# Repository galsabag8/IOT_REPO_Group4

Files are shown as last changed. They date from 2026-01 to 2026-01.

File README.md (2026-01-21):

## Conducting Baton Project by : Dor Abotbol, Shahar Payevsky & Gal Sabag
  
## Details about the project
In this project, we have developed an interactive system for learning musical conducting. The system allows the user to load a MIDI file and perform conducting gestures using a dedicated hardware baton. 
A custom-built GUI visualizes the conductor's movements in real-time to provide immediate feedback. Crucially, the system analyzes the user's gestures to dynamically adjust the music playback speed, ensuring the orchestra plays in sync with the conductor's rhythm.
 
## Folder description :
* Documentation: wiring diagram + basic operating instructions
* Unit Tests: tests for individual hardware components (input / output devices)
* App: includes the source code for the app code, the GUI written in HTML, the backend in python (Flask), and config file containing parameters for the code configuration
* Code : includes ESP32 source code for the esp side (firmware), and config file containing parameters for the code configuration 
* Assets: MIDI files used in this project

## Hardware we used in the project:
* ESP32
* IMU 9 degrees of freedom - type BMX055
* Button

## Arduino/ESP32 libraries used in this project:
* SPI (Standard Arduino/ESP32 Core)
* Madgwick Algorithm - (Local implementation included in source)

Implementation Note:

Unlike standard implementations that rely on external sensor libraries (e.g., Adafruit), this project utilizes direct register access via SPI to communicate with the IMU sensors. This ensures minimal latency and optimized high-speed data acquisition required for real-time conducting.
Sensor fusion is handled via a local implementation of the Madgwick algorithm, adapted directly from the original source code rather than using the pre-compiled library.

## Connection diagram:
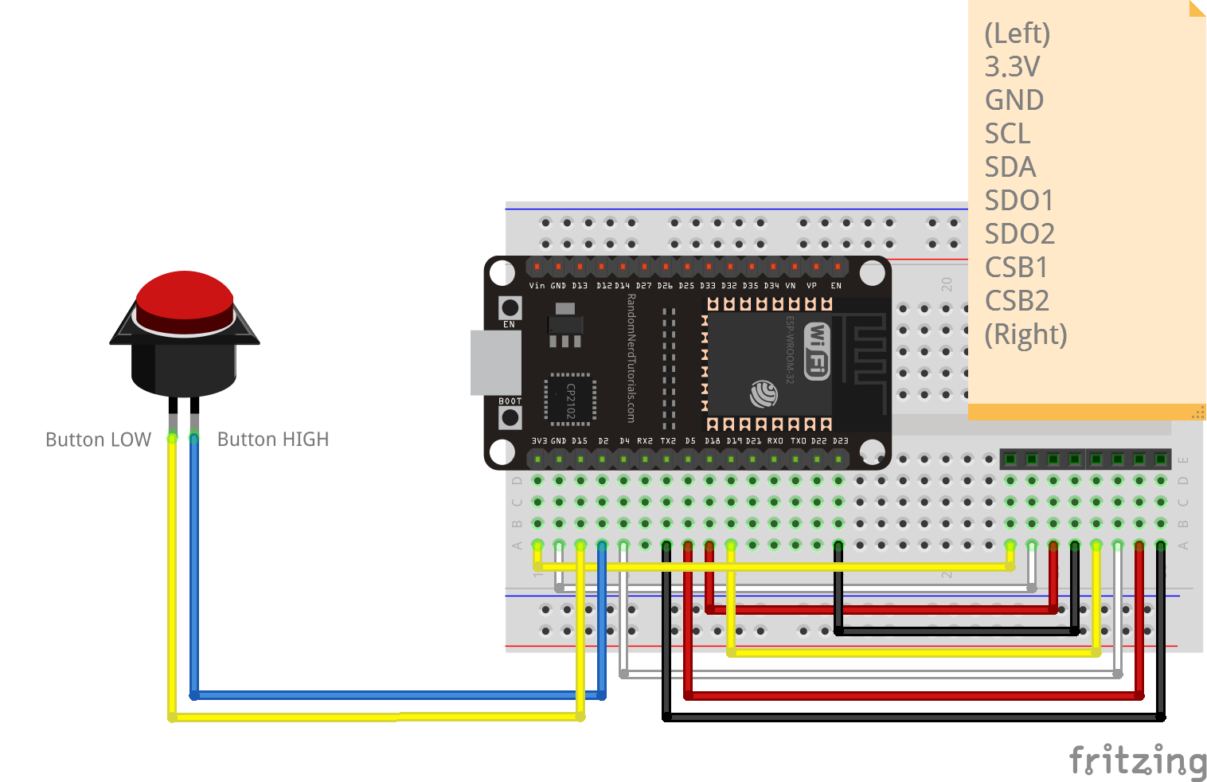
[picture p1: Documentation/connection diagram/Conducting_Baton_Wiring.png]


## Project Poster:
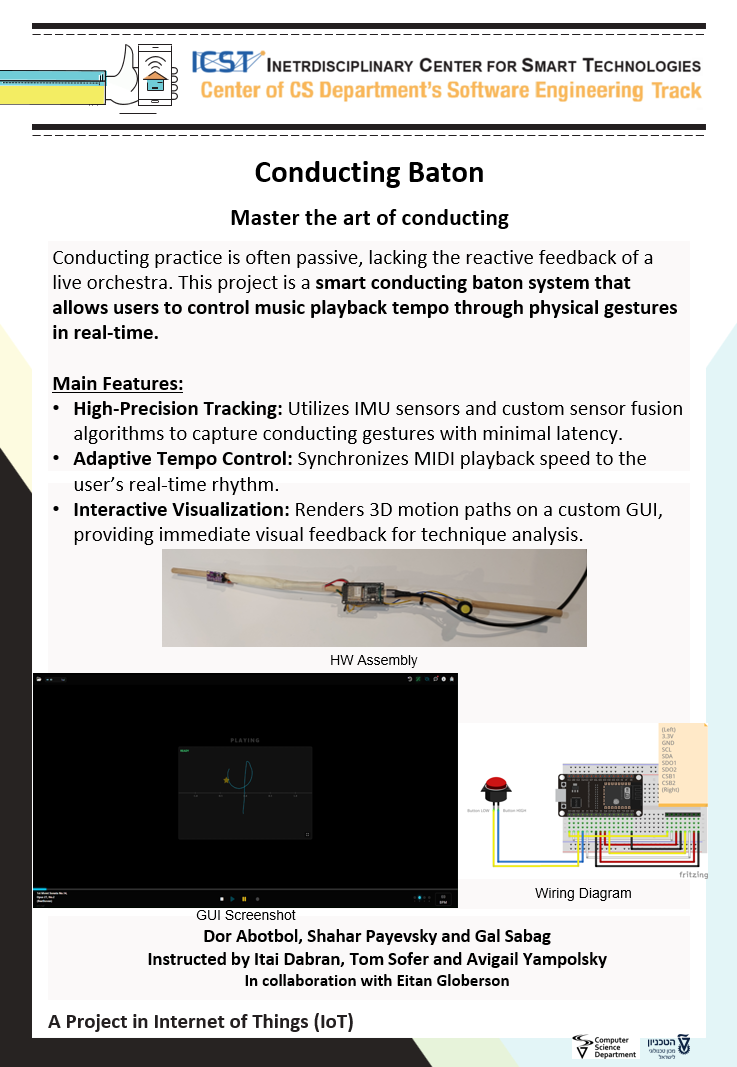
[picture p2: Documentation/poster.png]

 
This project is part of ICST - The Interdisciplinary Center for Smart Technologies, Taub Faculty of Computer Science, Technion
https://icst.cs.technion.ac.il/

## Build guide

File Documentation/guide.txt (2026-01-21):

Quick Guide:
Visualization: Click the eye to enable the 3D trail.
Calibration: Press R repeatedly until the wand appears stable (only relevant when visualization is open)
Confirm: Press Enter to lock calibration (only relevant when visualization is open)
Upload: Open a MIDI file (File button)
Start Warm‑Up: Press the wand button to begin warm‑up.
Perform: Do a full "box" motion (by the detected weight / conducting range). Music starts after warm‑up completes.
Record: Arm recording (red circle) before starting playback to save a CSV log of wand data and timing for later analysis.
Replay:Upload the original MIDI together with its CSV log to replay a recorded session visually and aurally.

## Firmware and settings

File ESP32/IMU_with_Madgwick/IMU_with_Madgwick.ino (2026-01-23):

/*
 * Project: Conductors Wand - Hybrid V1 (Vis + BPM)
 * Features: 
 * - High-speed Motion Data (for Visualization)
 * - Real-time BPM Calculation (for Music Control)
 * - Dual Filtering (Responsive for Vis, Smooth for Beats)
 */

#include <SPI.h>
#include "MadgwickAlgo.h"
#include "WeightDetectAlgo.h"
#include "config.h"

// --- Global params, defined as extern in config.h ---
bool DEBUG_MODE = false;
float CURRENT_THRESHOLD = W4_B1_THRESHOLD;

// --- Calibration Variables ---
bool gravity_calibrated = false;
int calibration_count = 0;
float gravity_accumulator = 0;
float gravity_mag = 9.80665f; // Default, will be updated

// --- Smoothing Constants ---
float accel_mag_history[SMOOTH_WINDOW] = {0};
int smooth_idx = 0;

// --- Global Variable for Time Signature ---
int TIME_SIGNATURE = 4; // Default to 4/4. Can be changed via Serial command later.
int next_expected_beat = 1;
int warmup_beats_target = 4;   
int warmup_beats_remaining = 4; //Number of beats remaining to complete warmup

// --- Beat Detection Variables ---
unsigned long last_beat_time = 0;
unsigned long last_valley_time = 0;

float smoothed_bpm = 60;
bool isPauseSent = false;

unsigned long beat_intervals[NUM_BEATS_AVG]; 
int beat_idx = 0;                      

unsigned long last_print_time = 0;

// Timing
unsigned long last_loop_time = 0;
float dt = 0.01f;
// --- Smoothed Accel Magnitude Variables ---
const int RECENT_HISTORY_SIZE = 20;
float recent_magnitudes[RECENT_HISTORY_SIZE] = {0};
int recent_idx = 0;

// Button LOGIC
bool buttonStatus = false;      // The parameter to toggle
int buttonReader;              // Current reading
int lastbuttonReader = LOW;    // Previous reading (Default LOW because of Pull-Down)
bool buttonEnabled = false;    // To track if button logic is active
bool firstButtonPress = true;  // Track if this is the first press

struct IMUData {
  float ax_phys, ay_phys, az_phys; // Physical acceleration (g)
  float gx_phys, gy_phys, gz_phys; // Physical gyroscope (deg/s)
  float gx_rad, gy_rad, gz_rad;    // Gyroscope in radians (rad/s)
};

IMUData currentIMUData;

struct VisualizationData {
  float x_vis, y_vis, z_vis;
  float screen_x, screen_y, screen_z;
};

VisualizationData currentVisData;

struct AccelerationData {
  float magnitude;
  float gyro_mag;
};

AccelerationData currentAccelData;

// --- State Definitions + variables ---
enum SystemState {
    STATE_IDLE,
    STATE_WARMUP,
    STATE_PLAYBACK
};

SystemState currentState = STATE_IDLE;
bool isGUICalibrationInProgress = false;
bool isFileLoaded = false;
bool sendConnectionStatus = true;
int connectionStatusTimeCounter = 0;


// --- Prototypes ---
void writeRegister(int csPin, byte reg, byte val, bool isAccel);
void readSensor(int csPin, byte startReg, int16_t *x, int16_t *y, int16_t *z, bool isAccel);
void updateBPM();
void detectBeat(float x, float z, float gyro_mag, float smoothed_mag);
bool handleMetric2(float x, float z, float magnitude, float gyro_mag);
bool handleMetric3(float x, float z, float magnitude, float gyro_mag);
bool handleMetric4(float x, float z, float magnitude, float gyro_mag);

void setup() {
  // 1. High Speed Serial (Matches Friend's code)
  Serial.begin(921600); 
  
  pinMode(CS_ACCEL, OUTPUT);
  pinMode(CS_GYRO, OUTPUT);
  pinMode(CS_MAG, OUTPUT);

  //Setup Button Pins
  // Configure D2 as a power source
  pinMode(SOURCE_PIN, OUTPUT);
  // Configure D15 as input with internal resistor to GND, If the button is NOT pressed, this pin will read LOW (0).
  pinMode(SENSING_PIN, INPUT_PULLDOWN);
  
  digitalWrite(CS_MAG, HIGH); 
  digitalWrite(CS_ACCEL, HIGH);
  digitalWrite(CS_GYRO, HIGH);
  digitalWrite(SOURCE_PIN, HIGH);
  
  delay(100); 

  // --- 2. Configure ACCEL (+/- 4g) ---
  SPI.begin(SPI_CLK, MISO_ACCEL, SPI_MOSI, CS_ACCEL);
  writeRegister(CS_ACCEL, 0x0F, 0x05, true); // Range +/- 4g
  writeRegister(CS_ACCEL, 0x10, 0x0C, true); // BW 125Hz
  SPI.end();

  delay(50);

  // --- 3. Configure GYRO (+/- 2000 dps) ---
  SPI.begin(SPI_CLK, MISO_GYRO, SPI_MOSI, CS_GYRO);
  writeRegister(CS_GYRO, 0x0F, 0x00, false); // Range +/- 2000dps
  writeRegister(CS_GYRO, 0x10, 0x02, false); // BW 116Hz
  SPI.end();
  
  delay(100); 
}

void loop() {
  // Always check for Serial commands regardless of state
  handleSerialCommands();
  
  // Check Button State
  checkButton();

  // 100Hz Loop
  unsigned long current_time = micros();
  if (current_time - last_loop_time < LOOP_DELAY_US) return;
  last_loop_time = micros();
  last_loop_time = current_time;

  readIMUData();

  if (!gravity_calibrated) {
    performGravityCalibration();
    return; // Wait until calibration is finished
  }

  // --- Run Embedded Algorithm (from MadgwickAlgo.cpp) ---
  updateOrientationAndLinearAccel();

  updateVisData();

  updateAndSmoothAccelMagnitude();

  //--- OUTPUT 1: Visualization Data (CSV) ---
  printXYZOutput();

  switch(currentState) {
    case STATE_IDLE:
      if (sendConnectionStatus) {
        connectionStatusTimeCounter++;
        if (connectionStatusTimeCounter >= 100) {
          connectionStatusTimeCounter = 0;
          Serial.println("STATUS: CONNECTED");
        }
      }
      return;
    case STATE_WARMUP:
      detectBeat(currentVisData.screen_x, 
                currentVisData.screen_z, 
                currentAccelData.gyro_mag, 
                currentAccelData.magnitude);
      return;
    case STATE_PLAYBACK:
      detectBeat(currentVisData.screen_x, 
                currentVisData.screen_z, 
                currentAccelData.gyro_mag, 
                currentAccelData.magnitude);
      if (millis() - last_beat_time > BPM_TIMEOUT) {
        printBPMOutput();
      }
      break;
    default:
      break;
  }
}

// --- Task: Serial Command Handling ---
void handleSerialCommands() {
  // --- 1. Check for incoming Command (Non-blocking) ---
  if (Serial.available() > 0) {
    String input = Serial.readStringUntil('\n');
    input.trim(); 

    if (input.equals("RESET")) {
      //If we got reset command from the GUI, reset the system state and variables
      // currentState = STATE_IDLE;
      // isGUICalibrationInProgress = false;
      // isFileLoaded = false;
      // firstButtonPress = true;
      // return;
      ESP.restart();
    }
    if (input.startsWith("PAUSE:")) {
      resetBeatDetectionState();
      int new_target = input.substring(6).toInt();
      warmup_beats_target = TIME_SIGNATURE + new_target - 1;
      warmup_beats_remaining = TIME_SIGNATURE + new_target - 1;
      next_expected_beat = 1;
      updateCurrentThreshold();
      currentState = STATE_WARMUP;
    }
    if (input.equals("CLOSING APP")) {
      ESP.restart();
    }
    if (input.equals("DEBUG:ON")) {
      DEBUG_MODE = true;
    }
    if (input.equals("DEBUG:OFF")) {
      DEBUG_MODE = false;
    }
    if (input.equals("WAND STATUS ACK")) {
      sendConnectionStatus = false;
      return;
    }
    if (input.equals("CALIBRATION STARTED")) {
      isGUICalibrationInProgress = true;
    }
    if (input.equals("CALIBRATION FINISHED")) {
      isGUICalibrationInProgress = false;
    }
    // Protocol: "SET_SIG:3"
    if (input.startsWith("WEIGHT:")) {
      int new_sig = input.substring(7).toInt();
      if (new_sig >= 2 && new_sig <= 4) {
        TIME_SIGNATURE = new_sig;
        next_expected_beat = 1; // Reset beat counter
        updateCurrentThreshold();
        isFileLoaded = true;
        warmup_beats_remaining = new_sig;
        warmup_beats_target = new_sig;
      }
    }
  }
}

void readIMUData() {
  int16_t raw_ax, raw_ay, raw_az;
  int16_t raw_gx, raw_gy, raw_gz;

  // --- Read Raw Data ---
  SPI.begin(SPI_CLK, MISO_ACCEL, SPI_MOSI, CS_ACCEL);
  readSensor(CS_ACCEL, 0x02, &raw_ax, &raw_ay, &raw_az, true);
  SPI.end(); 
  
  SPI.begin(SPI_CLK, MISO_GYRO, SPI_MOSI, CS_GYRO);
  readSensor(CS_GYRO, 0x02, &raw_gx, &raw_gy, &raw_gz, false);
  SPI.end();

  // --- Convert to Physical ---
  currentIMUData.ax_phys = raw_ax * ACCEL_SCALE;
  currentIMUData.ay_phys = raw_ay * ACCEL_SCALE;
  currentIMUData.az_phys = raw_az * ACCEL_SCALE;
  currentIMUData.gx_phys = raw_gx * GYRO_SCALE;
  currentIMUData.gy_phys = raw_gy * GYRO_SCALE;
  currentIMUData.gz_phys = raw_gz * GYRO_SCALE;
  currentIMUData.gx_rad = currentIMUData.gx_phys * (M_PI / 180.0f);
  currentIMUData.gy_rad = currentIMUData.gy_phys * (M_PI / 180.0f);
  currentIMUData.gz_rad = currentIMUData.gz_phys * (M_PI / 180.0f);
}

void performGravityCalibration() {
  float current_mag = sqrt(currentIMUData.ax_phys*currentIMUData.ax_phys 
                          + currentIMUData.ay_phys*currentIMUData.ay_phys 
                          + currentIMUData.az_phys*currentIMUData.az_phys);
      gravity_accumulator += current_mag;
      calibration_count++;
      
      if (calibration_count >= 100) {
          gravity_mag = gravity_accumulator / 100.0f;
          gravity_calibrated = true;
      }
}

void updateVisData() {
  // 5. Visualization Data [cite: 36]
  currentVisData.x_vis = 1.0f - 2.0f * (q2 * q2 + q3 * q3);
  currentVisData.y_vis = 2.0f * (q1 * q2 + q0 * q3);
  currentVisData.z_vis = 2.0f * (q1 * q3 - q0 * q2);

  currentVisData.screen_x = -currentVisData.y_vis;
  currentVisData.screen_y = currentVisData.x_vis;
  currentVisData.screen_z = -currentVisData.z_vis;
}

void updateOrientationAndLinearAccel() {
  MadgwickUpdate(currentIMUData.gx_rad, 
                  currentIMUData.gy_rad, 
                  currentIMUData.gz_rad, 
                  currentIMUData.ax_phys, 
                  currentIMUData.ay_phys, 
                  currentIMUData.az_phys,  
                  dt);

  // 3. Gravity Vector from Quaternions [cite: 33-35]
  float gravity_x = 2.0f * (q1 * q3 - q0 * q2);
  float gravity_y = 2.0f * (q0 * q1 + q2 * q3);
  float gravity_z = q0 * q0 - q1 * q1 - q2 * q2 + q3 * q3;

  // 4. Linear Acceleration (Subtract measured gravity)
  currentIMUData.ax_phys = currentIMUData.ax_phys - (gravity_x * gravity_mag);
  currentIMUData.ay_phys = currentIMUData.ay_phys - (gravity_y * gravity_mag);
  currentIMUData.az_phys = currentIMUData.az_phys - (gravity_z * gravity_mag);
}

void updateAndSmoothAccelMagnitude() {
  // Simple Smoothing for Accel Magnitude
  float raw_mag = sqrt(currentIMUData.ax_phys*currentIMUData.ax_phys 
                    + currentIMUData.ay_phys*currentIMUData.ay_phys 
                    + currentIMUData.az_phys*currentIMUData.az_phys);

   // Store in recent history
  recent_magnitudes[recent_idx] = raw_mag;
  recent_idx = (recent_idx + 1) % RECENT_HISTORY_SIZE;

  accel_mag_history[smooth_idx] = raw_mag;
  smooth_idx = (smooth_idx + 1) % SMOOTH_WINDOW;
  float smooth_mag = 0;
  for(int i=0; i<SMOOTH_WINDOW; i++) smooth_mag += accel_mag_history[i];
  smooth_mag /= SMOOTH_WINDOW;

  // --- CALIBRATION METRICS ---
  currentAccelData.magnitude = smooth_mag;
  currentAccelData.gyro_mag = sqrt(currentIMUData.gx_rad*currentIMUData.gx_rad 
                              + currentIMUData.gy_rad*currentIMUData.gy_rad 
                              + currentIMUData.gz_rad*currentIMUData.gz_rad);
}

void updateCurrentThreshold() {
  switch(TIME_SIGNATURE) {
    case 2:
      switch(next_expected_beat) {
        case 1:
          CURRENT_THRESHOLD = W2_B1_THRESHOLD;
          break;
        case 2:
          CURRENT_THRESHOLD = W2_B2_THRESHOLD;
          break;
      }
      break;
    case 3:
      switch(next_expected_beat) {
        case 1:
          CURRENT_THRESHOLD = W3_B1_THRESHOLD;
          break;
        case 2:
          CURRENT_THRESHOLD = W3_B2_THRESHOLD;
          break;
        case 3:
          CURRENT_THRESHOLD = W3_B3_THRESHOLD;
          break;
      }
      break;
    case 4:
      switch(next_expected_beat) {
        case 1:
          CURRENT_THRESHOLD = W4_B1_THRESHOLD;
          break;
        case 2:
          CURRENT_THRESHOLD = W4_B2_THRESHOLD;
          break;
        case 3:
          CURRENT_THRESHOLD = W4_B3_THRESHOLD;
          break;
        case 4:
          CURRENT_THRESHOLD = W4_B4_THRESHOLD;
          break;
      }
      break;
  }
}

void printXYZOutput() {
  //Format: DATA,x,y,z
  Serial.print("DATA,");
  Serial.print(currentVisData.screen_x, 4); 
  Serial.print(",");
  Serial.print(currentVisData.screen_y, 4); 
  Serial.print(",");
  Serial.println(currentVisData.screen_z, 4);
}

void printBPMOutput() {
  // --- Timeout Check (Force 0 BPM if idle) ---
  unsigned long now = millis();
  if (now - last_beat_time > BPM_TIMEOUT || now - last_valley_time > BPM_TIMEOUT) {
      smoothed_bpm = 0;
      next_expected_beat = 1;
      updateCurrentThreshold();
  }
  
  // --- Send BPM Update ---
  // We check this every loop, but print intermittently or on change
  if (millis() - last_print_time > PRINT_INTERVAL) {
      if (smoothed_bpm == 0 && isPauseSent) {
        return;
      }
      //Your Python app listens for "BPM: "
      Serial.print("BPM: ");
      Serial.println((int)smoothed_bpm); 
      last_print_time = millis();
      isPauseSent = (smoothed_bpm == 0) ? true : false;
  }
}

// --- HELPER: BPM CALCULATION ---
void updateBPM() {
    unsigned long now = millis();
    unsigned long interval = now - last_beat_time;
    last_beat_time = now;

    if (interval < MAX_BEAT_INTERVAL) {
      // Add to circular buffer
      beat_intervals[beat_idx] = interval;  
      beat_idx = (beat_idx + 1) % NUM_BEATS_AVG;

      // Average calculation
      unsigned long sum = 0;
      int valid_count = 0;
      for (int i = 0; i < NUM_BEATS_AVG; i++) {
        if (beat_intervals[i] > 0) { sum += beat_intervals[i]; valid_count++; }
      }
      
      float avg_interval = 0;
      if (valid_count > 0) avg_interval = (float)sum / valid_count;

      float raw_bpm_float = 0;
      if (avg_interval > 0) raw_bpm_float = 60000.0 / avg_interval;

      // Smoothing
      if (smoothed_bpm == 0) {
          smoothed_bpm = raw_bpm_float; 
      } else {
          float smooth_float = (BPM_SMOOTHING_ALPHA * raw_bpm_float) + ((1.0 - BPM_SMOOTHING_ALPHA) * smoothed_bpm);
          smoothed_bpm = (int)round(smooth_float);
      }
    }
}
// --- LOGIC: DETECT BEAT & BPM ---
void detectBeat(float x, float z, float gyro_mag, float magnitude) {
  bool beatConfirmed = false;
  switch (TIME_SIGNATURE) {
    case 2:
      beatConfirmed = handleMetric2(x, z, magnitude, gyro_mag);
      break;
    case 3:
      beatConfirmed = handleMetric3(x, z, magnitude, gyro_mag);
      break;
    case 4:
      beatConfirmed = handleMetric4(x, z,magnitude, gyro_mag);
      break;
  }

  if (beatConfirmed) {
      unsigned long now = millis();
      
      if (now - last_beat_time > MIN_BEAT_INTERVAL) {
          updateBPM();    

          next_expected_beat++;
          if (next_expected_beat > TIME_SIGNATURE) {
              next_expected_beat = 1;
          }
          updateCurrentThreshold();

          // --- NEW: Send Trigger to Python ---
          Serial.println("BEAT_TRIG");
          Serial.print("BEAT: "); Serial.println(next_expected_beat - 1 == 0 ? TIME_SIGNATURE : next_expected_beat - 1);

          if (currentState == STATE_PLAYBACK) {
            printBPMOutput();
          }
      }

      //Update warmup counter
      if (currentState == STATE_WARMUP) {
        warmup_beats_remaining--;
        if (warmup_beats_remaining == 0) {
          currentState = STATE_PLAYBACK;
        }
      }
  }
}
// --- Logic for 2/4 Time Signature ---
bool handleMetric2(float x, float z, float magnitude, float gyro_mag) {
  accel_tracker.update(magnitude);

  ValleyInfo valley_info = checkForValley(z, x, gyro_mag, accel_tracker.getJerkMagnitude());
  if (!valley_info.detected) return false;

  // --- IF WE ARE HERE, A VALLEY WAS JUST DETECTED ---

  if (valley_info.peak_jerk_during_descent < RESTING_ACCEL_CHANGE_THRESHOLD) {
    if (DEBUG_MODE){
      Serial.print("LOG: peak_jerk_during_descent: "); Serial.print(valley_info.peak_jerk_during_descent); Serial.print(" < threshold"); Serial.println(RESTING_ACCEL_CHANGE_THRESHOLD);
    }
    return false;
  }

  // Rule A: The wand must not be resting
  if (magnitude < RESTING_MAGNITUDE) {
    if(DEBUG_MODE){
      Serial.print("LOG: magnitude: "); Serial.println(magnitude);  Serial.print(" < Resting_Magnitude"); Serial.println(RESTING_MAGNITUDE);
    }
    return false;
  }
  
  last_valley_time = millis();

  // Rule B: Check Beat Expectations
  switch (next_expected_beat) {
    case 1:
        if (checkBeat1LogicWithWeight2(magnitude, z, x, next_expected_beat, valley_info)) return true;
        break;
    case 2:
        if (checkBeat2LogicWithWeight2(magnitude, z, x, next_expected_beat, valley_info)) return true;
        break;
    default:
      break;
  }
  
  // if we get here, we detect a beat but it didn't match expectations, so returing to beat1
  next_expected_beat = 1;
  updateCurrentThreshold();
  // --- NEW: Send Trigger to Python ---
  Serial.println("BEAT: 0");
  if (currentState == STATE_WARMUP) {
    warmup_beats_remaining = warmup_beats_target;
    resetBeatDetectionState();
  }

  return false;
}

// --- Logic for 3/4 Time Signature ---
// Pattern: 1 (Down), 2 (Out/Right), 3 (Up)
bool handleMetric3(float x, float z, float magnitude, float gyro_mag) {
  accel_tracker.update(magnitude);

  ValleyInfo valley_info = checkForValley(z, x, gyro_mag, accel_tracker.getJerkMagnitude());
  if (!valley_info.detected) return false;

  // --- IF WE ARE HERE, A VALLEY WAS JUST DETECTED ---

  if (valley_info.peak_jerk_during_descent < RESTING_ACCEL_CHANGE_THRESHOLD) {
    if (DEBUG_MODE){
      Serial.print("LOG: peak_jerk_during_descent: "); Serial.print(valley_info.peak_jerk_during_descent); Serial.print(" < threshold"); Serial.println(RESTING_ACCEL_CHANGE_THRESHOLD);
    }
    return false;
  }

  // Rule A: The wand must not be resting
  if (magnitude < RESTING_MAGNITUDE) {
    if(DEBUG_MODE){
      Serial.print("LOG: magnitude: "); Serial.println(magnitude);  Serial.print(" < Resting_Magnitude"); Serial.println(RESTING_MAGNITUDE);
    }
    return false;
  }
  
  last_valley_time = millis();

  // Rule B: Check Beat Expectations
  switch (next_expected_beat) {
    case 1:
        if (checkBeat1LogicWithWeight3(magnitude, z, x, next_expected_beat, valley_info)) return true;
        break;
    case 2:
        if (checkBeat2LogicWithWeight3(magnitude, z, x, next_expected_beat, valley_info)) return true;
        break;
    case 3:
        if (checkBeat3LogicWithWeight3(magnitude, z, x, next_expected_beat, valley_info)) return true;
        break;
    default:
      break;
  }
  // if we get here, we detect a beat but it didn't match expectations, so returing to beat1
  
  next_expected_beat = 1;
  updateCurrentThreshold();
  // --- NEW: Send Trigger to Python ---
  Serial.println("BEAT: 0");
  if (currentState == STATE_WARMUP) {
    warmup_beats_remaining = warmup_beats_target;
    resetBeatDetectionState();
  }

  return false;
}

// --- Logic for 4/4 Time Signature ---
// Pattern: 1 (Down), 2 (In/Left), 3 (Out/Right), 4 (Up)
bool handleMetric4(float x, float z, float magnitude, float gyro_mag) {
  accel_tracker.update(magnitude);

  ValleyInfo valley_info = checkForValley(z, x, gyro_mag, accel_tracker.getJerkMagnitude());
  if (!valley_info.detected) return false;

  // --- IF WE ARE HERE, A VALLEY WAS JUST DETECTED ---

  if (valley_info.peak_jerk_during_descent < RESTING_ACCEL_CHANGE_THRESHOLD) {
    if (DEBUG_MODE){
      Serial.print("LOG: peak_jerk_during_descent: "); Serial.print(valley_info.peak_jerk_during_descent); Serial.print(" < threshold"); Serial.println(RESTING_ACCEL_CHANGE_THRESHOLD);
    }
    return false;
  }

  // Rule A: The wand must not be resting
  if (magnitude < RESTING_MAGNITUDE) {
    if(DEBUG_MODE){
      Serial.print("LOG: magnitude: "); Serial.println(magnitude);  Serial.print(" < Resting_Magnitude"); Serial.println(RESTING_MAGNITUDE);
    }
    return false;
  }
  
  last_valley_time = millis();

  // Rule B: Check Beat Expectations
  switch (next_expected_beat) {
    case 1:
        if (checkBeat1LogicWithWeight4(magnitude, z, x, next_expected_beat, valley_info)) return true;
        break;
    case 2:
        if (checkBeat2LogicWithWeight4(magnitude, z, x, next_expected_beat, valley_info)) return true;
        break;
    case 3:
        if (checkBeat3LogicWithWeight4(magnitude, z, x, next_expected_beat, valley_info)) return true;
        break;
    case 4:
        if (checkBeat4LogicWithWeight4(magnitude, z, x, next_expected_beat, valley_info)) return true;
        break;
    default:
      break;
  }
  // if we get here, we detect a beat but it didn't match expectations, so returing to beat1
  
  next_expected_beat = 1;
  // --- NEW: Send Trigger to Python ---
  Serial.println("BEAT: 0");  
  updateCurrentThreshold();
  if (currentState == STATE_WARMUP) {
    warmup_beats_remaining = warmup_beats_target;
    resetBeatDetectionState();
  }
  return false;
}

// --- SPI Helpers ---
void writeRegister(int csPin, byte reg, byte val, bool isAccel) {
  SPI.beginTransaction(SPISettings(1000000, MSBFIRST, SPI_MODE0)); 
  digitalWrite(csPin, LOW); 
  SPI.transfer(reg & 0x7F); 
  SPI.transfer(val);
  digitalWrite(csPin, HIGH); 
  SPI.endTransaction();
}

void readSensor(int csPin, byte startReg, int16_t *x, int16_t *y, int16_t *z, bool isAccel) {
  byte data[6]; 
  SPI.beginTransaction(SPISettings(2000000, MSBFIRST, SPI_MODE0)); 
  digitalWrite(csPin, LOW); 
  SPI.transfer(startReg | 0x80); 
  for (int i = 0; i < 6; i++) {
    data[i] = SPI.transfer(0x00);
  }
  digitalWrite(csPin, HIGH); 
  SPI.endTransaction();

  if (isAccel) {
      *x = (int16_t)((data[1] << 8) | data[0]) >> 4; 
      *y = (int16_t)((data[3] << 8) | data[2]) >> 4;
      *z = (int16_t)((data[5] << 8) | data[4]) >> 4;
  } else {
      *x = (int16_t)((data[1] << 8) | data[0]);
      *y = (int16_t)((data[3] << 8) | data[2]);
      *z = (int16_t)((data[5] << 8) | data[4]);
  }
}

unsigned long lastDebounceTime = 0;
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

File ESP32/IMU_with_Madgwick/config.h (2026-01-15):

#ifndef CONFIG_H
#define CONFIG_H

#include <Arduino.h>

// =================================================================
//			HARDWARE & WIRING (IMU_with_Madgwick.ino)
// =================================================================
// These define which pins on your microcontroller connect to the IMU sensors.
#define SPI_CLK      18
#define SPI_MOSI     23
#define MISO_ACCEL   19  
#define MISO_GYRO    4   
#define CS_ACCEL     5
#define CS_GYRO      17
#define CS_MAG       14   
#define SOURCE_PIN   2
#define SENSING_PIN  15

// =================================================================
//					SYSTEM CONTROL & MODES
// =================================================================
// for logging in WeightDetectAlgo.cpp
extern bool DEBUG_MODE;

// =================================================================
//					BUTTON PARAMETERS
// =================================================================
// for debounce in .ino
#define DEBOUNCE_DELAY 50

// =================================================================
//				SENSOR CALIBRATION & FILTERING
// =================================================================
// ACCEL_SCALE: 1.95mg/LSB * 9.80665 (for +/- 4g range).
const float ACCEL_SCALE = 0.01912f; 
// GYRO_SCALE: 1/16.4 dps/LSB (for +/- 2000 dps range).
const float GYRO_SCALE  = 1.0f / 16.4f; 

// Madgwick filter gain. Higher = faster response but more noise. 
// Lower = smoother orientation but more lag.
const float MADGWICK_BETA = 0.03f; 

// Size of the moving average window for acceleration magnitude.
// Increasing this makes beat detection more stable but less responsive.
const int SMOOTH_WINDOW = 5; 

// =================================================================
//		  BEAT DETECTION THRESHOLDS (WeightDetectAlgo.cpp)
// =================================================================

/**
 * SAMPLES_TO_CONFIRM_REVERSAL: Number of consecutive samples to confirm a trend reversal.
 * Helps filter out noise-induced false reversals.
 */
const int SAMPLES_TO_CONFIRM_REVERSAL = 2;  


const float RESTING_MAGNITUDE = 1.5f; 

/**
 * ACCEL_HISTORY_SIZE: Number of past acceleration values to store for velocity calculation.
 */
const int ACCEL_HISTORY_SIZE = 5;  // Configurable window size

/**
 * VELOCITY_ALPHA: EMA alpha for velocity smoothing.
 * Higher = responsive to quick changes; Lower = filters out jitter
 */
const float VELOCITY_ALPHA = 0.3f;

/**
 * MIN_VELOCITY_FOR_VALLEY: Speed required to detect a change in direction.
 * If the wand is moving slower than this, the algorithm won't look for a "valley."
 */
const float MIN_VELOCITY_FOR_VALLEY = 0.0075f;

/**
 * ACCEL_CHANGE_SMOOTHING: EMA alpha for smoothing magnitude changes.
 * Higher = responsive to quick changes; Lower = filters out jitter
 */
const float ACCEL_CHANGE_ALPHA = 0.2f;

/**
 * RESTING_ACCEL_CHANGE_THRESHOLD: Maximum magnitude change to be considered "at rest"
 * Used to detect when baton is not moving (for filtering out static tilts)
 */
const float RESTING_ACCEL_CHANGE_THRESHOLD = 0.80f;

// // Threshold for considering motion "vertical" (minimal rotation)
// const float VERTICAL_MOTION_THRESHOLD = 0.15f;  // Tune this!

// // Threshold for considering motion "vertical" (minimal rotation)
// const float VERTICAL_NOISE_THRESHOLD = 0.01f;  // Tune this!
// =================================================================
//						THRESHOLDS
// =================================================================
const float W4_B1_THRESHOLD = 0.15f;
const float W4_B2_THRESHOLD = 0.15f;
const float W4_B3_THRESHOLD = 0.15f;
const float W4_B4_THRESHOLD = 0.15f;
const float W3_B1_THRESHOLD = 0.15f;
const float W3_B2_THRESHOLD = 0.15f;
const float W3_B3_THRESHOLD = 0.15f;
const float W2_B1_THRESHOLD = 0.15f;
const float W2_B2_THRESHOLD = 0.15f;
extern float CURRENT_THRESHOLD;

// =================================================================
//						BPM & TIMING LOGIC
// =================================================================
// Loop speed in microseconds (10000us = 100Hz).
const int LOOP_DELAY_US = 10000; 

// Shortest possible time between two beats to prevent double-triggering.
const int MIN_BEAT_INTERVAL = 250; 

// Longest time between beats before the sequence resets.
const int MAX_BEAT_INTERVAL = 2000; 

// Time in ms of inactivity before BPM is forced to 0.
const unsigned long BPM_TIMEOUT = 3000; 

// Alpha for the EMA filter (0.0 to 1.0). 
// Higher = BPM updates faster; Lower = BPM is more stable/averaged.
const float BPM_SMOOTHING_ALPHA = 0.2f; 

// Number of beats to include in the rolling average BPM.
const int NUM_BEATS_AVG = 2; 

// How often to print data to the Serial port (in ms).
const int PRINT_INTERVAL = 100;

#endif

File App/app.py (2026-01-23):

import os
import subprocess 
import sys
import threading
import time
import mido
import atexit
import json
from mido import tempo2bpm
from flask import Flask, render_template, request, jsonify
import socket
import csv
import config
import numpy as np

# --- IMPORT YOUR LISTENER MODULE ---
import listener 

app = Flask(__name__)

# --- GLOBAL STATE ---
playback_state = {
    "bpm": 67.0,
    "is_playing": False,
    "is_paused": False,
    "wand_enabled": False, 
    "filename": None,
    "thread": None,
    "current_ticks": 0,
    "total_ticks": 0,
    "ticks_per_beat": 480,
    "original_duration": 0.0,
    "weight": 0,
    "record_enabled": False,
    "replay_active": False,
    "wand_connected": False,
    "last_beat_received": 0,
    "button_state": False,
    "correction_matrix": None,
    "debug_enabled": False,
    "debug_queue": [],
    "next_beat": 1
}

# --- GUI PROCESS KEEPER ---
gui_process = None
is_cleaning_up = False

def matrix_receiver():
    """Listens for correction matrix updates from trace.py"""
    sock = socket.socket(socket.AF_INET, socket.SOCK_DGRAM)
    sock.bind((config.IP, config.PORT_MATRIX))
    sock.setblocking(False)
    
    while True:
        try:
            data, _ = sock.recvfrom(1024)
            msg = json.loads(data.decode('utf-8'))
            if 'matrix' in msg:
                matrix_values = msg['matrix']
                playback_state['correction_matrix'] = np.array(matrix_values, dtype=np.float32).reshape(3, 3)
        except BlockingIOError:
            time.sleep(0.05)
        except json.JSONDecodeError:
            pass
        except Exception as e:
            print(f"Matrix Receiver Error: {e}")
            time.sleep(0.1)

# --- Helper to send replay matrix to trace.py via UDP ---
def send_replay_matrix_to_trace(matrix):
    """Send a replay matrix to trace.py via UDP with MATRIX: prefix"""
    try:
        sock = socket.socket(socket.AF_INET, socket.SOCK_DGRAM)
        if matrix is not None:
            # Format: MATRIX:v1,v2,v3,v4,v5,v6,v7,v8,v9
            matrix_values = matrix.flatten().tolist()
            matrix_str = ",".join([str(v) for v in matrix_values])
            matrix_data = f"MATRIX:{matrix_str}"
        else:
            matrix_data = "MATRIX:CLEAR"
        sock.sendto(matrix_data.encode('utf-8'), (config.IP, config.PORT_VIS))
    except Exception as e:
        print(f"--- APP: Failed to send replay matrix: {e} ---")

# --- HELPER: MANAGE GUI WINDOW ---
def open_gui():
    """ Opens the Visualization Window if not already open """
    global gui_process
    if gui_process is None:
        print("--- APP: Launching GUI Window (trace.py)... ---")
        # Ensure 'trace.py' is in the same directory
        gui_process = subprocess.Popen([sys.executable, 'trace.py'])

def close_gui():
    """ Closes the Visualization Window if open """
    global gui_process
    if gui_process:
        print("--- APP: Closing GUI Window... ---")
        gui_process.terminate()
        gui_process = None

def cleanup():
    """ Kills the GUI and stops all playback immediately """
    global is_cleaning_up
    if is_cleaning_up:
        return
    is_cleaning_up = True
    print("--- APP: Cleaning up resources... ---")
    
    # 1. Flag the system to stop
    playback_state["is_playing"] = False
    playback_state["wand_enabled"] = False
    
    # 2. Silence all MIDI notes (The "Panic" Loop)
    # We open a temporary port just to send the silence commands
    try:
        with mido.open_output() as port:
            for ch in range(16):
                port.send(mido.Message('control_change', channel=ch, control=123, value=0)) # All Notes Off
                port.send(mido.Message('control_change', channel=ch, control=64, value=0))  # Sustain Pedal Off
    except:
        pass

    try:
            udp_sock = socket.socket(socket.AF_INET, socket.SOCK_DGRAM)
            msg = "CLOSING APP"
            udp_sock.sendto(msg.encode('utf-8'), ("127.0.0.1", config.PORT_CMD))
    except Exception as e:
            print(f"--- APP: Failed to send reset command: {e} ---")

    # 3. Kill the Visualizer Window

    close_gui()

atexit.register(cleanup)

# --- UDP LISTENER ---
def udp_music_listener():
    udp_sock = socket.socket(socket.AF_INET, socket.SOCK_DGRAM)
    udp_sock.bind(("127.0.0.1", 5005)) 
    udp_sock.setblocking(False)
    
    while playback_state["is_playing"]:
        try:
            data, addr = udp_sock.recvfrom(1024)
            line = data.decode('utf-8').strip()
            if playback_state["replay_active"]:
                continue

            if line.startswith("BPM: "):
                if playback_state["wand_enabled"]:
                    try:
                        raw_val = float(line.split(":")[1].strip())
                        apply_bpm_logic(raw_val)
                    except ValueError:
                        pass
            
        except BlockingIOError:
            time.sleep(0.01)
        except Exception as e:
            print(f"UDP Error: {e}")
            time.sleep(0.1)
    udp_sock.close()


os.makedirs(config.UPLOAD_FOLDER, exist_ok=True)
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

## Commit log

2025-11-23 added camera unitest
2025-11-23 gyroandaccelro unitest
2025-11-23 last version - without magnetomter
2025-12-10 new frontend design+buttons improvement
2025-12-15 with arduino integration
2025-12-16 My updates description
    [wand_data_2_dor.csv, wand_data_4_80bpm.csv]
2025-12-21 all madgwick code in the IMU + added weight extraction from MIDI + detecting 2/4 motion
2025-12-21 add calibration INO + detect beat for all 4 weights
    [wand_data_2_50bpm.csv, wand_data_2_80bpm.csv, wand_data_3_50bpm.csv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]
2025-12-21 still need to be checked but: added dynamic weight sent to IMU + added warm up mode
2025-12-23 fixed some things regarding last commits
    [IMU_with_Madgwick.ino, app.py]
2025-12-24 Add white-red-green color logic to wand button
2025-12-24 Update play engine to stop track when wand mode is active and wand is disconnected
2025-12-24 disable/enable play button according to connection status in wand mode
2025-12-24 Update wand_enabled to false on reset
    [app.py]
2025-12-25 worked on the ESP32 in order to make it cleaner and clearer. + updated listener.py to COM4 + updated gitignore
2025-12-25 switched the ESP32 files to the ESP32 folder
2025-12-28 new calibration + better midi parser
2025-12-28 added X axis to visualize + BEAT sign in visualizition + improved weight detect algo
2025-12-28 maybe a better version and more stable for the gyro param? still need to be checked
2025-12-30 Implement LED indication
2025-12-31 Adding config file to the ESP32 code files
2025-12-31 print BEAT event to serial ports to activate LEDs
2026-01-07 Implement button logic + tested for ESP32 implementation
2026-01-11 current version, still has problems to identify UP motion and need to check if right-left thresholds are correct
    [IMU_with_Madgwick.ino, WeightDetectAlgo.cpp, config.h]
2026-01-11 minor fixes + disable dynamic threshold atm
    [IMU_with_Madgwick.ino, WeightDetectAlgo.cpp]
2026-01-11 fixed listener and double RESET
    [app.py, listener.py]
2026-01-12 reset warmup counter in case of error during warmup
    [IMU_with_Madgwick.ino]
2026-01-12 Print BPM when recognizing betas
2026-01-12 fix not pausing error
    [IMU_with_Madgwick.ino]
2026-01-12 Clear debug prints in esp
2026-01-13 better buttons integration(record,vis)
2026-01-13 Fix notification for Dor + print BPM 0 only once
    [IMU_with_Madgwick.ino, WeightDetectAlgo.cpp]
2026-01-13 detecting next beat needs alignment("moving" music to end of current beat)
2026-01-15 fixed trace messages
2026-01-17 Button unitest
2026-01-17 created an assets directory with MIDI files and csv recordings
    [wand_data_1.csv, wand_data_2.csv, wand_data_2_50bpm.csv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]
2026-01-18 restarting the ESP32 with CLOSING APP
2026-01-18 added a log that says you cant cancel calibration after a file was loaded
2026-01-20 fixed ESC to recalibrate
    [trace.py]
2026-01-20 better prints
2026-01-21 Upload wiring diagram and add it to README
2026-01-21 Remove redundant folder + Change GUI folder to App folder
    [wand_data_2_50bpm.csv, wand_data_2_80bpm.csv, wand_data_2_dor.csv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]
2026-01-21 Upload Fritzing wiring diagram
    [Conducting_Baton_Wiring.fzz]
2026-01-21 Remove redundant files
    [wand_data_1.csv, wand_data_2.csv, wand_data_2_50bpm.csv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]
2026-01-22 force calibration after replay
2026-01-23 fixed replay with pauses. disabled recordBtn after calibration confirmed
    [app.py, trace.py]
2026-01-23 fixed problems with warmup counting and with replay logic
    [IMU_with_Madgwick.ino, app.py]
2026-01-23 insures recording button is red and seen
